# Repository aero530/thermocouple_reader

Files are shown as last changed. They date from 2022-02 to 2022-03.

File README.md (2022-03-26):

# thermocouple_reader

Handheld 8 channel temperature sensor.  Supports up to 8 type k thermocouples.  Displays temperatures in F or C.

The design uses off the shelf microcontroller board and LCD with a custom thermocouple input board.  The 8 thermocouple channels are muxed to a single interface IC to reduce component costs.  The microcontroller cycles through the mux inputs to read each channel in series, sampling multiple time to mitigate input noise.

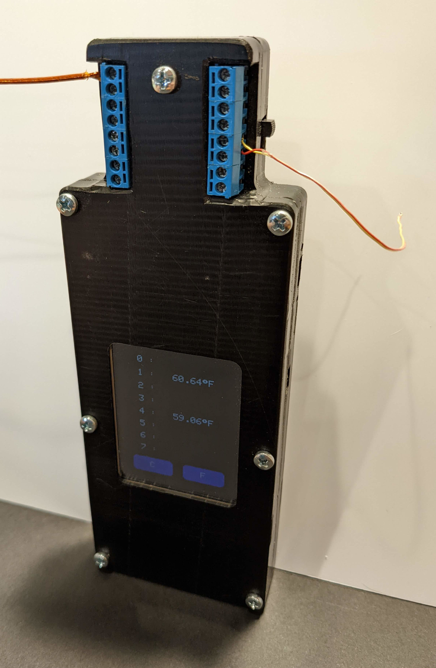
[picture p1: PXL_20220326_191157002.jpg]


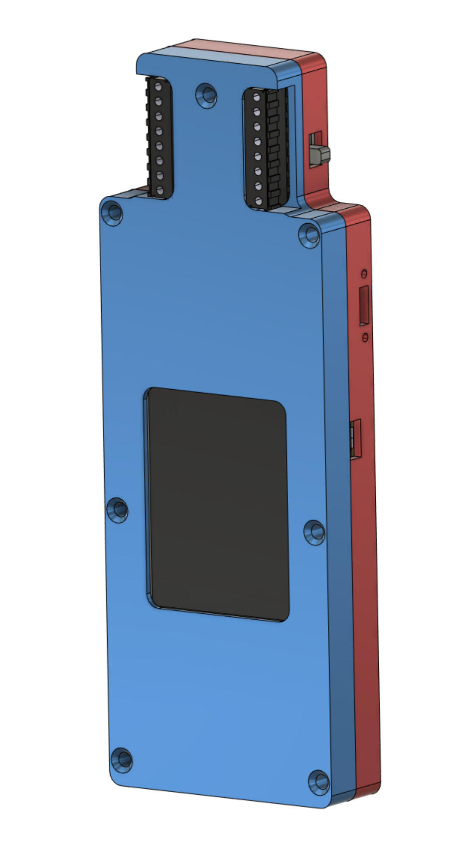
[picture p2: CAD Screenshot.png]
cad


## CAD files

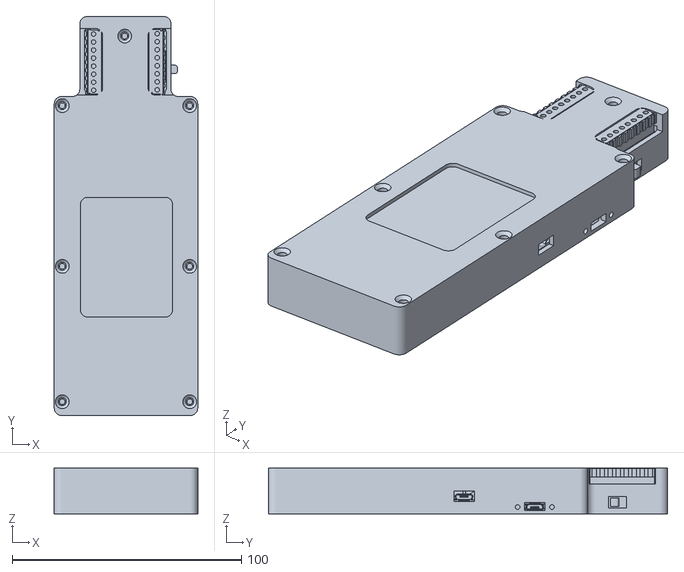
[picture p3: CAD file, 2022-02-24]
mechanical/Thermocouple Reader v43.stl
62.6 x 173.9 x 20.0

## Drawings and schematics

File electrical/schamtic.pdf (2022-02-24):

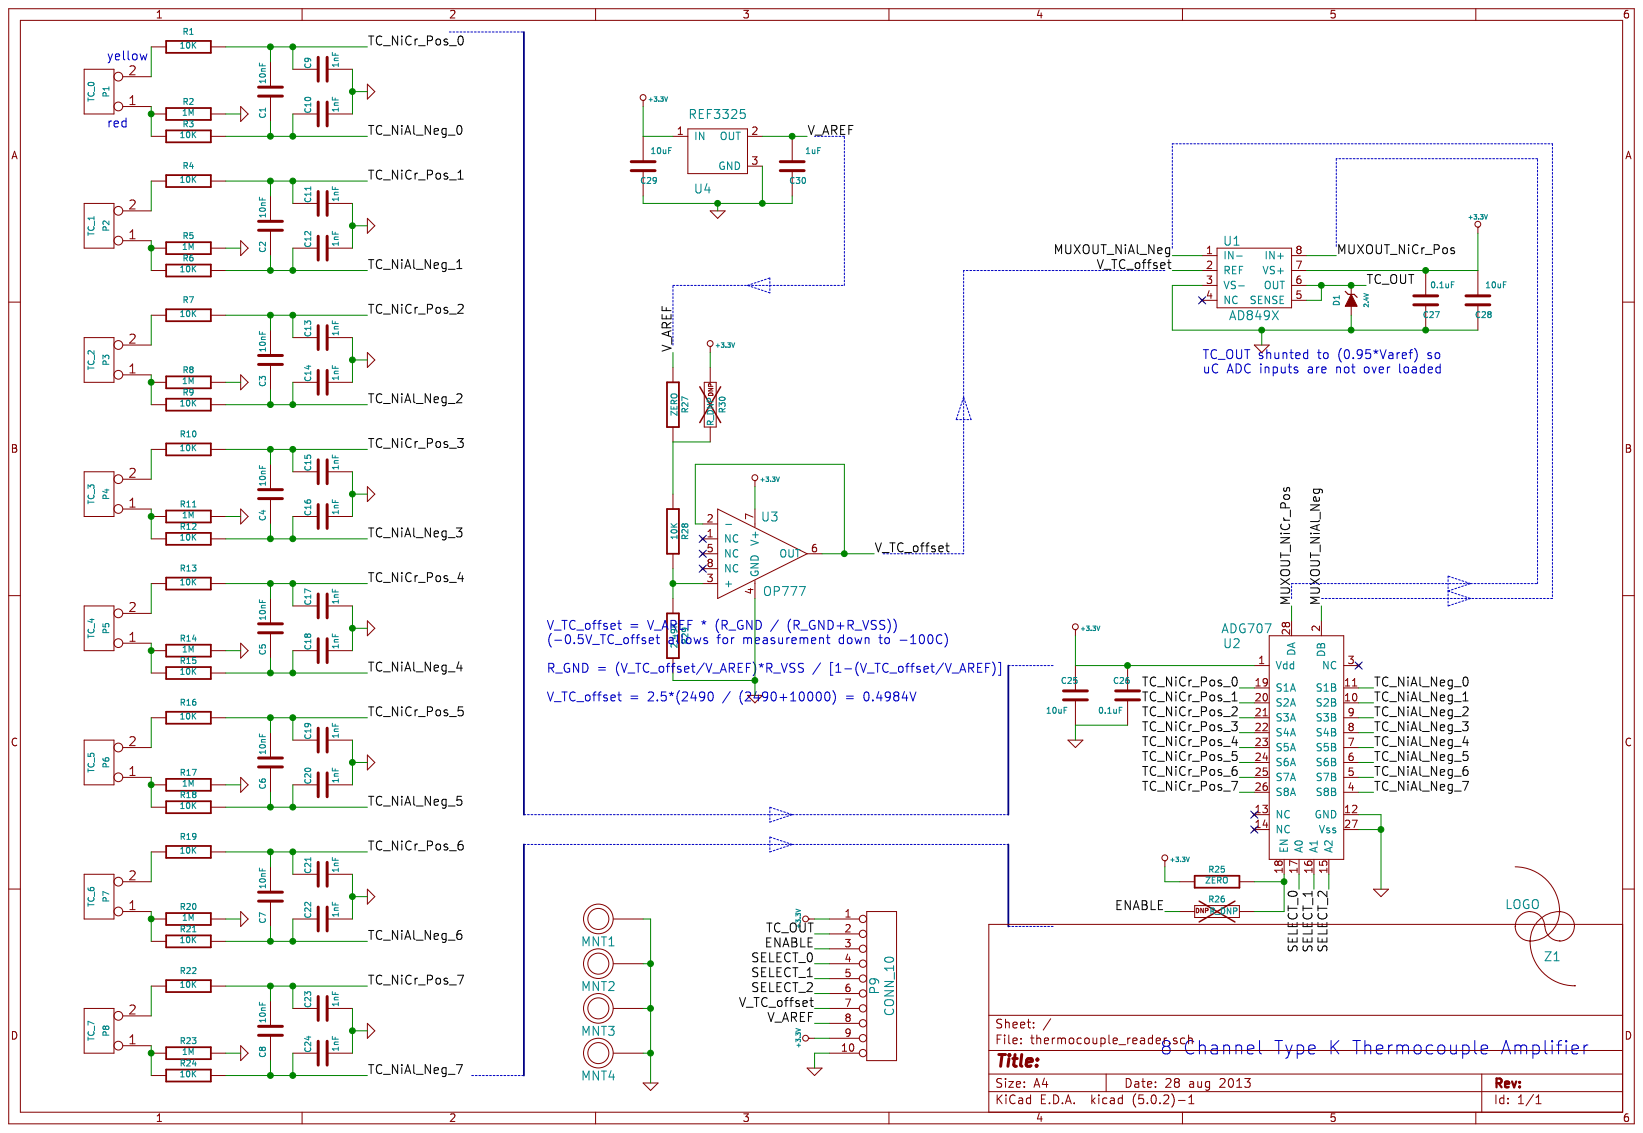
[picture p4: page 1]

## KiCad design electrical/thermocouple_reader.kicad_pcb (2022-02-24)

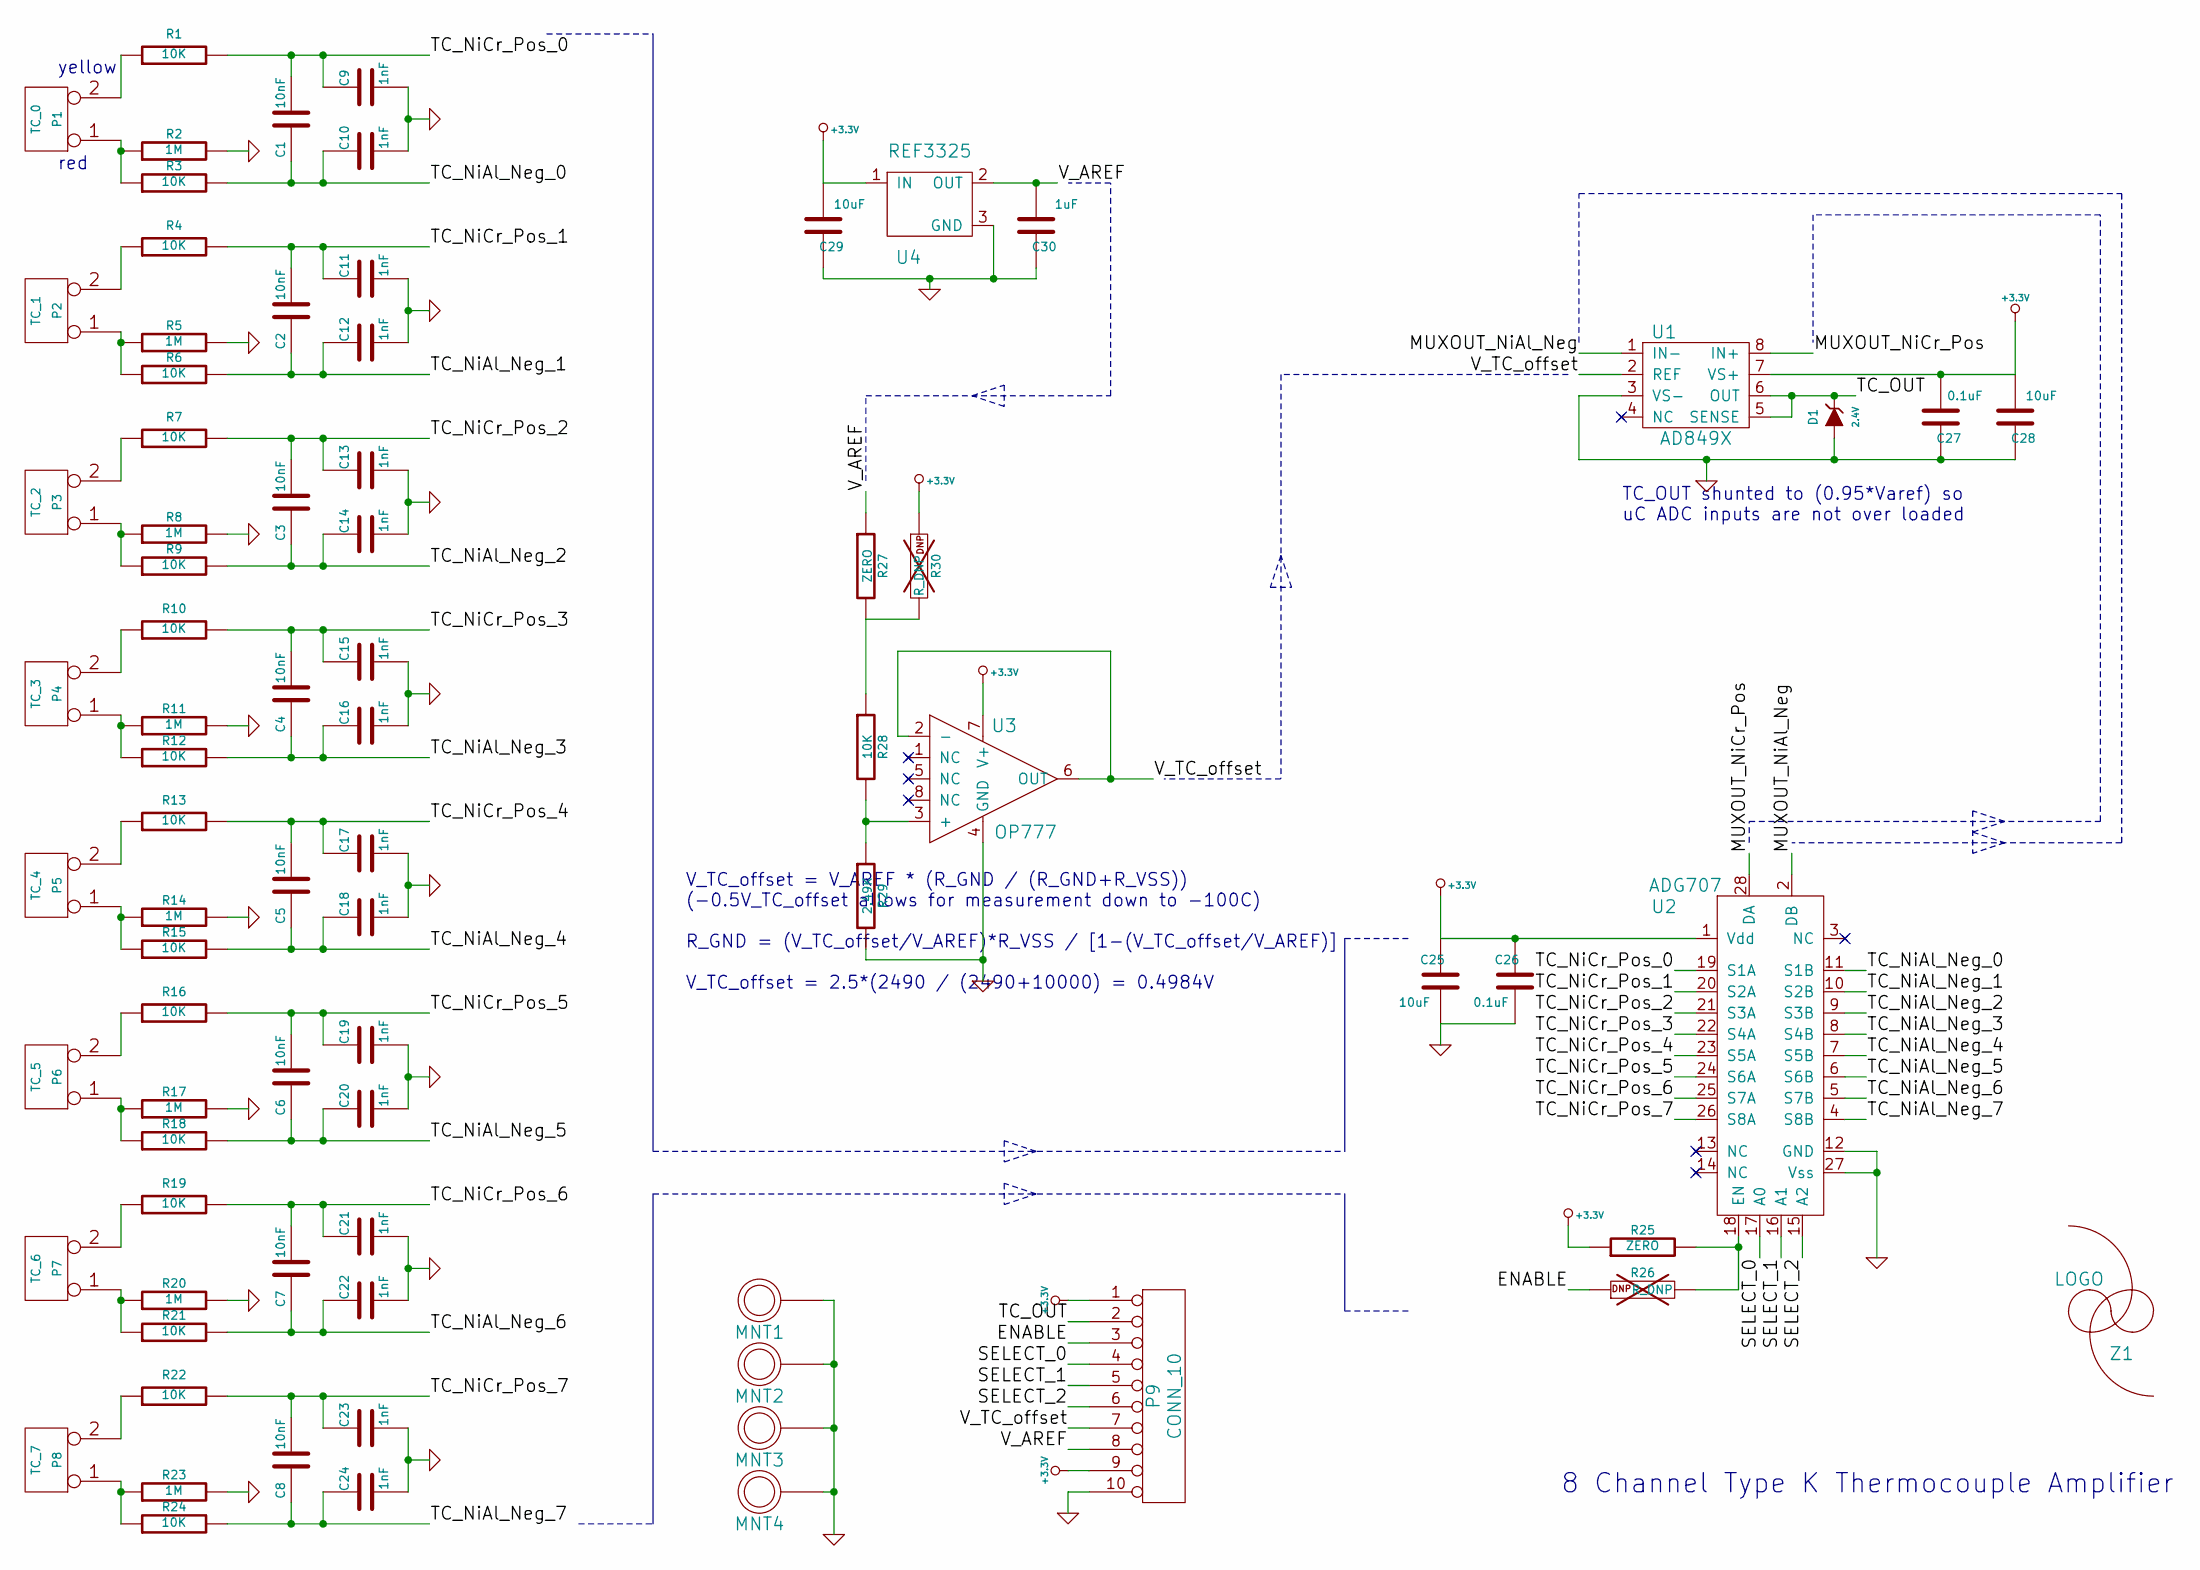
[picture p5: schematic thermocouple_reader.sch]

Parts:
C1, C2, C3, C4, C5, C6, C7, C8: 10nF
C9, C10, C11, C12, C13, C14, C15, C16, C17, C18, C19, C20, C21, C22, C23, C24: 1nF
C25, C28, C29: 10uF
C26, C27: 0.1uF
C30: 1uF
D1: 2.4V; Part Number MMBZ5221B-7-F
MNT1, MNT2, MNT3, MNT4: 4_40_HOLE
P1: TC_0
P2: TC_1
P3: TC_2
P4: TC_3
P5: TC_4
P6: TC_5
P7: TC_6
P8: TC_7
P9: CONN_10
R1, R3, R4, R6, R7, R9, R10, R12, R13, R15, R16, R18, R19, R21, R22, R24, R28: 10K
R2, R5, R8, R11, R14, R17, R20, R23: 1M
R25, R27: ZERO
R26, R30: R_DNP
R29: 2.49K
U1: AD849X
U2: ADG707
U3: OP777
U4: REF3325
Z1: LOGO

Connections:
+3.3V: C25.1, C26.1, C27.2, C28.2, C29.2, P9.1, P9.9, R25.1, R30.1, U1.7 (VS+), U2.1 (Vdd), U3.7 (V+), U4.1 (IN)
/ENABLE: P9.3, R26.1
/MUXOUT_NiAl_Neg: U1.1 (IN-), U2.2 (DB)
/MUXOUT_NiCr_Pos: U1.8 (IN+), U2.28 (DA)
/SELECT_0: P9.4, U2.17 (A0)
/SELECT_1: P9.5, U2.16 (A1)
/SELECT_2: P9.6, U2.15 (A2)
/TC_NiAl_Neg_0: C1.1, C10.1, R3.2, U2.11 (S1B)
/TC_NiAl_Neg_1: C2.1, C12.1, R6.2, U2.10 (S2B)
/TC_NiAl_Neg_2: C3.1, C14.1, R9.2, U2.9 (S3B)
/TC_NiAl_Neg_3: C4.1, C16.1, R12.2, U2.8 (S4B)
/TC_NiAl_Neg_4: C5.1, C18.1, R15.2, U2.7 (S5B)
/TC_NiAl_Neg_5: C6.1, C20.1, R18.2, U2.6 (S6B)
/TC_NiAl_Neg_6: C7.1, C22.1, R21.2, U2.5 (S7B)
/TC_NiAl_Neg_7: C8.1, C24.1, R24.2, U2.4 (S8B)
/TC_NiCr_Pos_0: C1.2, C9.1, R1.2, U2.19 (S1A)
/TC_NiCr_Pos_1: C2.2, C11.1, R4.2, U2.20 (S2A)
/TC_NiCr_Pos_2: C3.2, C13.1, R7.2, U2.21 (S3A)
/TC_NiCr_Pos_3: C4.2, C15.1, R10.2, U2.22 (S4A)
/TC_NiCr_Pos_4: C5.2, C17.1, R13.2, U2.23 (S5A)
/TC_NiCr_Pos_5: C6.2, C19.1, R16.2, U2.24 (S6A)
/TC_NiCr_Pos_6: C7.2, C21.1, R19.2, U2.25 (S7A)
/TC_NiCr_Pos_7: C8.2, C23.1, R22.2, U2.26 (S8A)
/TC_OUT: D1.3 (K), P9.2, U1.5 (SENSE), U1.6 (OUT)
/V_AREF: C30.2, P9.8, R27.1, U4.2 (OUT)
/V_TC_offset: P9.7, U1.2 (REF), U3.2 (-), U3.6 (OUT)
GND: C9.2, C10.2, C11.2, C12.2, C13.2, C14.2, C15.2, C16.2, C17.2, C18.2, C19.2, C20.2, C21.2, C22.2, C23.2, C24.2, C25.2, C26.2, C27.1, C28.1, C29.1, C30.1, D1.1 (A), MNT1.1, MNT2.1, MNT3.1, MNT4.1, P9.10, R2.2, R5.2, R8.2, R11.2, R14.2, R17.2, R20.2, R23.2, R29.2, U1.3 (VS-), U2.12 (GND), U2.27 (Vss), U3.4 (GND), U4.3 (GND)
unnamed: P8.2 (PM), R22.1
unnamed: P5.2 (PM), R13.1
unnamed: P4.2 (PM), R10.1
unnamed: P7.2 (PM), R19.1
unnamed: P6.2 (PM), R16.1
unnamed: R25.2, R26.2, U2.18 (EN)
unnamed: R27.2, R28.1, R30.2
unnamed: P3.2 (PM), R7.1
unnamed: P3.1, R8.1, R9.1
unnamed: P2.2 (PM), R4.1
unnamed: P2.1, R5.1, R6.1
unnamed: P4.1, R11.1, R12.1
unnamed: P1.1, R2.1, R3.1
unnamed: P5.1, R14.1, R15.1
unnamed: P1.2 (PM), R1.1
unnamed: R28.2, R29.1, U3.3 (+)
unnamed: P6.1, R17.1, R18.1
unnamed: P8.1, R23.1, R24.1
unnamed: P7.1, R20.1, R21.1

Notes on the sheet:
TC_OUT shunted to (0.95*Varef) so uC ADC inputs are not over loaded
V_TC_offset = V_AREF * (R_GND / (R_GND+R_VSS)) (-0.5V_TC_offset allows for measurement down to -100C) R_GND = (V_TC_offset/V_AREF)*R_VSS / [1-(V_TC_offset/V_AREF)] V_TC_offset = 2.5*(2490 / (2490+10000) = 0.4984V
8 Channel Type K Thermocouple Amplifier
yellow
red

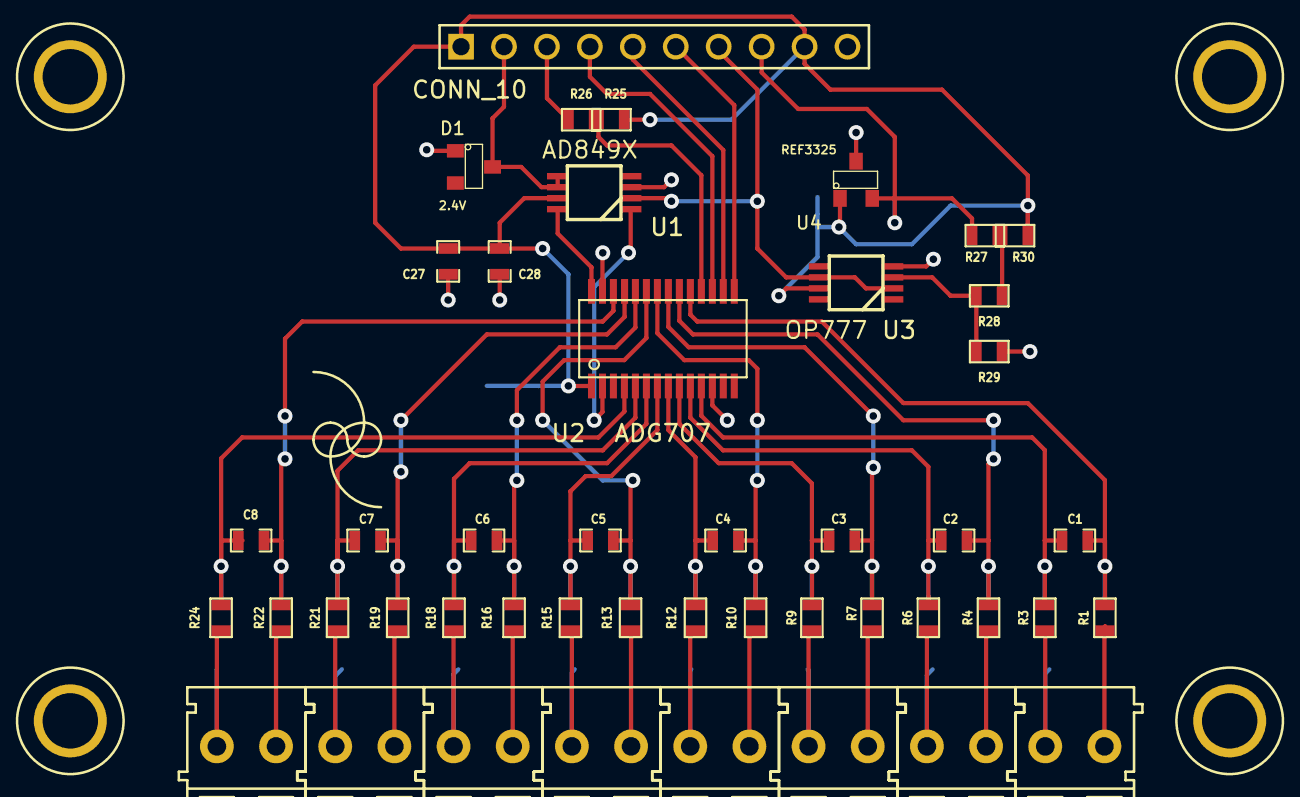
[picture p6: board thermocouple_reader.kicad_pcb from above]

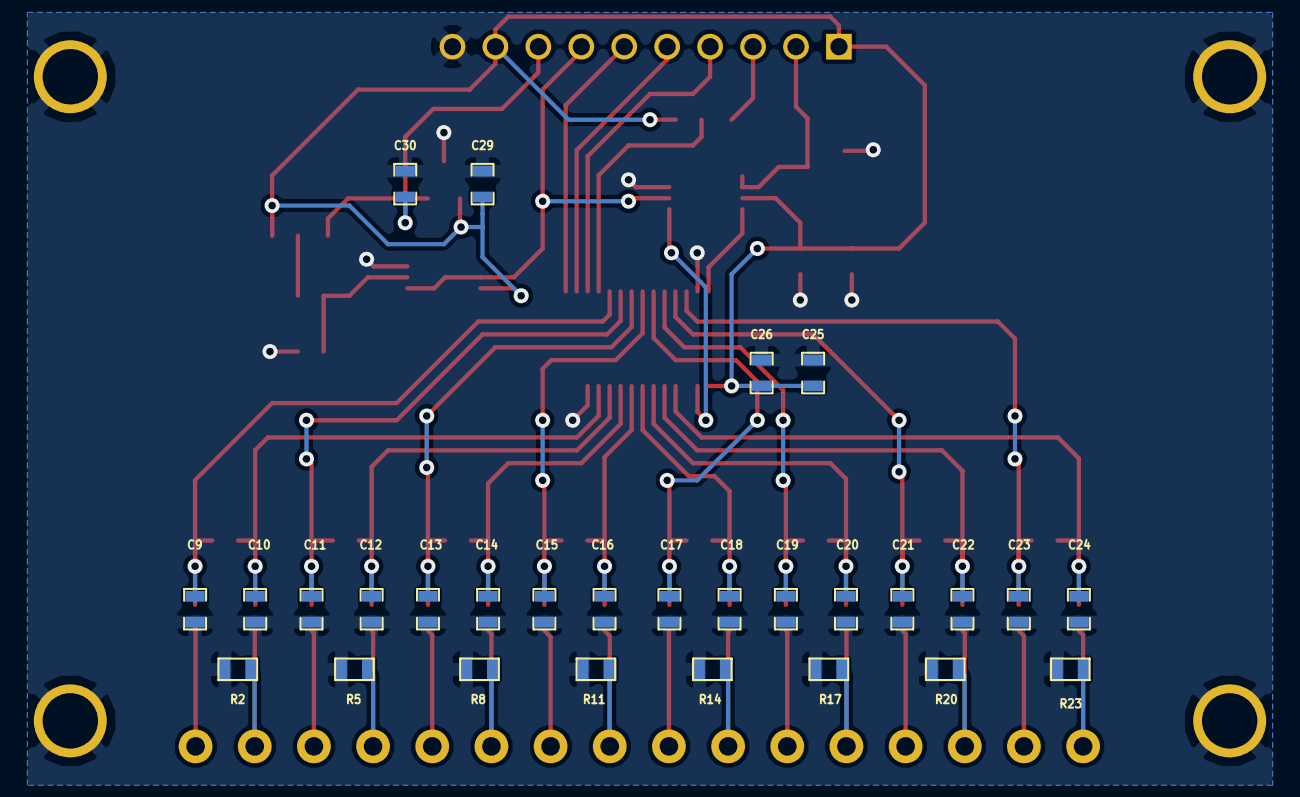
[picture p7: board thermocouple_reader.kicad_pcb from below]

Board: 2 copper layers, 79 parts (28 on the bottom side), 46 nets.

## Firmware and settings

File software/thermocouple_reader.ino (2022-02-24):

#include <Wire.h>

#include "AR1000.h"
#include "TLC59108.h"
#include "SPI.h"
#include "Adafruit_GFX.h"
#include "Adafruit_ILI9341.h"

/* Display backlight */
#define HW_RESET_PIN 9 // not connected
#define i2cAddrBacklight TLC59108::I2C_ADDR::BASE
TLC59108 leds(i2cAddrBacklight);

/* Display tft */
#define TFT_DC 0
#define TFT_CS 17
#define TFT_MOSI 16
#define TFT_CLK 15
#define TFT_RST -5
#define TFT_MISO 14

// Use hardware SPI and the above for CS/DC
Adafruit_ILI9341 tft = Adafruit_ILI9341(TFT_CS, TFT_DC);

/* Display touchscreen */
// touch panel configured to send pen down on touch and continuously while being touched
const byte TOUCH_IRQ_PIN = 7;
#define i2cAddrTouchController AR1000::I2C_ADDR::BASE
AR1000 touchController(i2cAddrTouchController);
volatile byte touchReportReady = LOW;

void touchEvent() {
  touchReportReady = HIGH;
}

/* TC Reader */

#define TC_ENABLE 21 // A3
#define TC_SEL0 20 // A2
#define TC_SEL1 19 // A1
#define TC_SEL2 18 // A0
int TC_OUTPUT = A4;
int TC_OFFSET = A5;

int tcMatrix[8][3] = {
  {0,0,0},
  {1,0,0},
  {0,1,0},
  {1,1,0},
  {1,1,1},
  {0,1,1},
  {1,0,1},
  {0,0,1},
};

const int numReadings = 200;

float tcReading[8];                  // the running total
float offsetReading[8];                // the average
float tcAvg[8];
float offsetAvg[8];
float temperature[8];
uint8_t units = 0; // 0=C, 1=F0

#define TEMP_MAX 350

/* Display tft */
/* Initialize buttons for use on display */
// create 2 buttons
char buttonlabels[2][6] = {"C", "F"};
uint16_t buttoncolors[2] = {ILI9341_DARKGREEN, ILI9341_RED};
Adafruit_GFX_Button buttons[2];

void setup() {
  Serial.begin(115200);
//  while (!Serial) {
    //; // wait for serial port to connect. Needed for native USB
//  }
  
  pinMode(TC_ENABLE, OUTPUT);
  pinMode(TC_SEL0, OUTPUT);
  pinMode(TC_SEL1, OUTPUT);
  pinMode(TC_SEL2, OUTPUT);

  digitalWrite(TC_ENABLE, HIGH);
  digitalWrite(TC_SEL0, HIGH);
  digitalWrite(TC_SEL1, LOW);
  digitalWrite(TC_SEL2, LOW);
  
  pinMode(TOUCH_IRQ_PIN, INPUT);
  attachInterrupt(digitalPinToInterrupt(TOUCH_IRQ_PIN), touchEvent, RISING);

  Wire.begin();
  
  touchController.init();
  
  leds.init(HW_RESET_PIN);
  leds.setLedOutputMode(TLC59108::LED_MODE::PWM_IND);
  leds.setBrightness(0, 0x00);
  delay(200);
  leds.setBrightness(0, 0xff);

  tft.begin();

  // Initialize content to display on screen
  tft.fillScreen(ILI9341_BLACK);

  uint8_t buttonTextScale = 2;
  buttons[0].initButton(&tft, 20+45, 320-60+20, 90, 40, ILI9341_PURPLE, ILI9341_BLUE, ILI9341_WHITE, buttonlabels[0], buttonTextScale);
  buttons[0].drawButton();
  buttons[1].initButton(&tft, 130+45, 320-60+20, 90, 40, ILI9341_PURPLE, ILI9341_BLUE, ILI9341_WHITE, buttonlabels[1], buttonTextScale);
  buttons[1].drawButton();

  uint16_t textBaseY = 20;
  uint16_t textLineSpacing = 30;
  tft.setTextColor(ILI9341_WHITE);
  tft.setTextSize(2);
  for (uint8_t i=0; i<8; i++) {
    tft.setCursor(40, textBaseY+textLineSpacing*i);
    tft.print(i);
    tft.print(" : 000.00");
    delay(5);
  }
    
  Serial.println("Setup Complete");
}

void loop(){
  uint8_t touchLocation[2];
  uint16_t pressX;
  uint16_t pressY;
  
  uint16_t textBaseY = 20;
  uint16_t textLineSpacing = 30;
  
  if (touchReportReady) {
    uint8_t pen = touchController.readTouchReport(touchLocation);
    touchReportReady = LOW;
    // Convert touch panel coordinates (1 to 30 on each axis) into display coordinates (320x240)
    pressX = touchLocation[1]*(240/30);
    pressY = 320 - touchLocation[2]*(320/30);
  } else {
    pressX = -1;
    pressY = -1;
  }

  // go thru all the buttons, checking if they were pressed
  for (uint8_t b=0; b<2; b++) {
    if (buttons[b].contains(pressX, pressY)) {
      //Serial.print("Pressing: "); Serial.println(b);
      buttons[b].press(true);  // tell the button it is pressed
      units = b;
    } else {
      buttons[b].press(false);  // tell the button it is NOT pressed
    }
  }

  // now we can ask the buttons if their state has changed
  for (uint8_t b=0; b<2; b++) {
    if (buttons[b].justReleased()) {
      // Serial.print("Released: "); Serial.println(b);
      buttons[b].drawButton();  // draw normal
    }
    if (buttons[b].justPressed()) {
      buttons[b].drawButton(true);  // draw invert!
    }
  }
    
  tft.setTextColor(ILI9341_WHITE, ILI9341_BLACK);
  tft.setTextSize(2);

  for (uint8_t j=0; j<8; j++) {
    digitalWrite(TC_ENABLE, LOW);
    digitalWrite(TC_SEL0, tcMatrix[j][0]);
    digitalWrite(TC_SEL1, tcMatrix[j][1]);
    digitalWrite(TC_SEL2, tcMatrix[j][2]);
    digitalWrite(TC_ENABLE, HIGH);
    
    delay(1);

    tcReading[j] = 0;
    for (int readIndex=0; readIndex<numReadings; readIndex++) {
      // add the reading to the total:
      tcReading[j] = tcReading[j] + analogRead(TC_OUTPUT);
    }
    tcAvg[j] = tcReading[j] / numReadings;

    offsetReading[j] = 0;
    for (int readIndex=0; readIndex<numReadings; readIndex++) {
      // add the reading to the total:
      offsetReading[j] = offsetReading[j] + analogRead(TC_OFFSET);
    }
    offsetAvg[j] = offsetReading[j] / numReadings;

    // AD8497 TC amplifier outputs at 5mV / C
    // ADC on Arduinos is 10bit => max reading of 1023
    // ADC is referenced to 3.3V
    // Temperature = ADCreading / 1023 * 3.3[V] * 1000[mV/V] / 5[mV/C]
    // Temperature = ADCreading * 0.64516129
    temperature[j] = (float (tcAvg[j]-offsetAvg[j]))*0.64516129;
    
    if (temperature[j] > TEMP_MAX) {
      temperature[j] = 999;
    }
  }

  

  for (uint8_t i=0; i<8; i++) {
    tft.setCursor(40, textBaseY+textLineSpacing*i);
    tft.print(i);
    tft.print(" : ");
    
    if (temperature[i]==999) {
       tft.print("         ");
    } else {
      if (temperature[i]>=100) {
        tft.print(" ");
      } else if (temperature[i] > 0) {
        tft.print("  ");
      } else if (temperature[i] < 0 & temperature[i] > -100) {
        tft.print(" ");
      } else if (temperature[i] == 0) {
        tft.print("   ");
      }
      
      if (units == 1) {
        //temperature[j] = temperature[j]*9/5 + 32;
        Serial.print(temperature[i]*9/5 + 32,2);
        Serial.print("°");
        Serial.print("F ");
        
        tft.print(temperature[i]*9/5 + 32,2);
        tft.print((char)247);
        tft.print("F");
      } else {
        Serial.print(temperature[i],2);
        Serial.print("°");
        Serial.print("C ");
        
        tft.print(temperature[i],2);
        tft.print((char)247);
        tft.print("C");
      }
    }
  }
  Serial.println("");
  
}

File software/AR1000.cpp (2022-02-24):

/*
 * AR1000: Arduino library to control TI AR1000/AR1000F/TLC59208 LED drivers
 * 
 * (C) 2013 Christopher Smith <chrylis@gmail.com>
 * 
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
 * You should have received a copy of the GNU Lesser General Public License
 * along with this program.  If not, see <http://www.gnu.org/licenses/>.
 */

extern "C"
{
#include <inttypes.h>
}

#include "AR1000.h"

void AR1000::setDefaultI2C(TwoWire i2c_default) {
   AR1000::i2c_default = i2c_default;
}

AR1000::AR1000(TwoWire i2c, const byte i2c_address): i2c(i2c), addr(i2c_address) {
}

AR1000::AR1000(const byte i2c_address): addr(i2c_address) {
   i2c = Wire;
}

uint8_t AR1000::setRegister(const uint8_t reg, const uint8_t value) const {
  uint8_t dataSend[10];
  uint8_t dataReceive[10];

  uint8_t registerStartAddr = 0x00;
  uint8_t replySize = sendCommand(dataReceive, AR1000::COMMAND::REGISTER_START_ADDRESS_REQUEST, 0, dataSend);
  if (replySize > 0) {
    registerStartAddr = dataReceive[0];
  } else {
    Serial.println("can't get register start address");
    return -1;
  }

  dataSend[0] = 0x00;
  dataSend[1] = registerStartAddr + reg;
  dataSend[2] = 0x01;
  dataSend[3] = value;

  replySize = sendCommand(dataReceive, AR1000::COMMAND::REGISTER_WRITE, 4, dataSend);
    
  if (replySize == 0) { // reply came back with success but does not return data
    return 1;
  } else if (replySize > 0) {
    for(uint8_t index=0; index<replySize; index++) {
      Serial.print(dataReceive[index],HEX);
      Serial.print(" ");
    }
    Serial.println("write failed with some returned data");
    return -1;
  } else {
    Serial.println("write failed");
    return -1;
  }
}

uint8_t AR1000::readRegister(const uint8_t reg) const {
  uint8_t dataSend[10];
  uint8_t dataReceive[10];

  uint8_t registerStartAddr = 0x00;
  uint8_t replySize = sendCommand(dataReceive, AR1000::COMMAND::REGISTER_START_ADDRESS_REQUEST, 0, dataSend);
  if (replySize > 0) {
    registerStartAddr = dataReceive[0];
  } else {
    Serial.println("can't get register start address");
    return -1;
  }

  dataSend[0] = 0x00;
  dataSend[1] = registerStartAddr + reg;
  dataSend[2] = 0x01;

  replySize = sendCommand(dataReceive, AR1000::COMMAND::REGISTER_READ, 3, dataSend);
  if (replySize == 1) {
    return dataReceive[0];
  } else if (replySize > 0) {
    for(uint8_t index=0; index<replySize; index++) {
      Serial.print(dataReceive[index],HEX);
      Serial.print(" ");
    }
    Serial.println("read failed with more than one reply");
    return -1;
  } else {
    Serial.println("read failed");
    return -1;
  }
}

uint8_t AR1000::sendCommand(uint8_t *dataReceive, const uint8_t command, const uint8_t dataSize, uint8_t *dataSend) const {
  bool error = true;
  int reply_size = 0x00;
  
  // dataSize = size of dataIn
  
  Wire.beginTransmission(addr);
  Wire.write(0x00); // init i2c. a bit...magic
  Wire.write(0x55); // header = 0x55
  Wire.write((uint8_t) (dataSize+1)); // size = # bytes to follow
  Wire.write(command); // get version

  if (dataSize > 0) {
   for (int i = 0; i < dataSize; i++) {
      Wire.write(dataSend[i]); // get version
    } 
  }
  
  Wire.endTransmission();    // stop transmitting
  //delay(5);
  Wire.requestFrom(addr, 2);

  uint8_t header = Wire.read();
  if (header = 0x55) {
    reply_size = Wire.read(); // receive a byte as character
//    Serial.print("  reply size ");
//    Serial.print(reply_size);
    if (reply_size > 0) {
      Wire.requestFrom(addr, reply_size);
      uint8_t replyStatus = Wire.read();
      uint8_t replyCommand = Wire.read();
      if (replyStatus == 0 && replyCommand == command) { // if status = 0 the command was successful
        error = false;
        // Serial.print("command ");
        // Serial.println(Wire.read(),HEX);
        reply_size = reply_size - 2; // first two bytes already read
        for (int i = 0; i < reply_size; i++) {
          uint8_t c = Wire.read(); // receive a byte as character
          // Serial.println(c,HEX);         // print the character
          (*dataReceive) = (uint8_t) c;
          dataReceive++;
        } 
        return reply_size; 
      } else {
        Serial.print("reply status error: ");
        if (replyStatus == 0x01) {
          Serial.println("command unrecognized");
        } else if (replyStatus == 0x03) {
          Serial.println("header unrecognized");
        } else if (replyStatus == 0x04) {
          Serial.println("command time out");
        } else if (replyStatus == 0xFC) {
          Serial.println("cancel calibration mode");
        } else {
          Serial.println(replyStatus,HEX);  
        }
      }  
    }
  }

  if (error) {
    delay(5);
    sendCommand(dataReceive, command, dataSize, dataSend);  
  }
}
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

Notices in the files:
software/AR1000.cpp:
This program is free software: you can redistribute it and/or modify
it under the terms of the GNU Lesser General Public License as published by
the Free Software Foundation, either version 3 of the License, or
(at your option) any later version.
